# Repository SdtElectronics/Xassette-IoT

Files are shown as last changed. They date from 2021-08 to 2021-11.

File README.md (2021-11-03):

# Xassette IoT
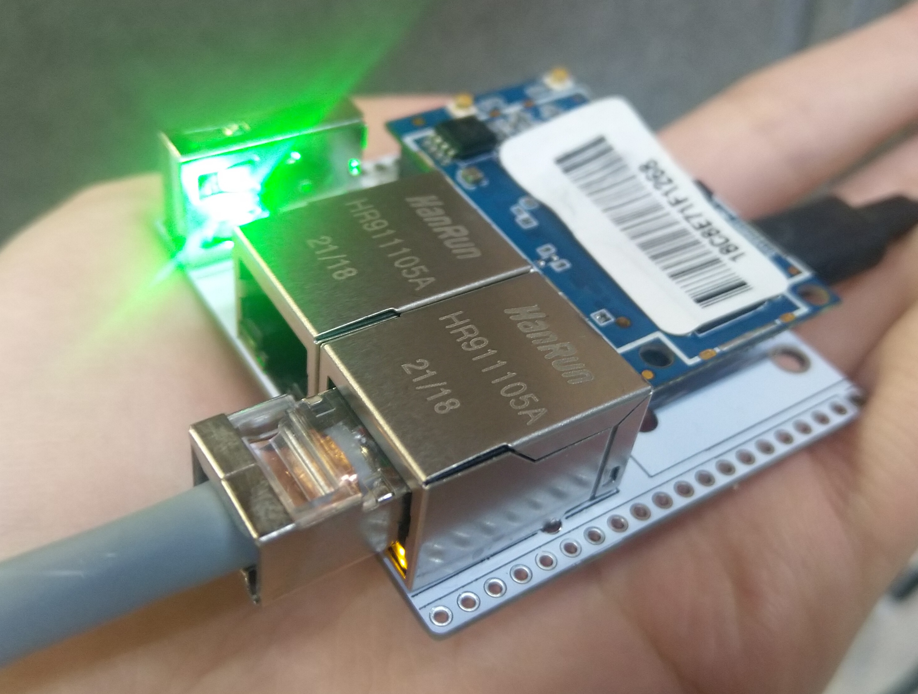
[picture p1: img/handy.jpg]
handy

## Hardware Resources
* SoC: MediaTek MT7628 1xMIPS 24Kc@580Mhz
* RAM: 64MB DDR2
* ROM: 8M SPI flash EN25Q64
* WLAN: 802.11n, 2T2R, speed up to 300Mbps
* EPHY: 5×100M with 2 onboard RJ-45 ports
* USB: 1×USB2.0 HS
* Connectivity: 2×UART¹, 1×I2C, 1×I2S, 1×SPI², 1×SDIO³, 4×PWM

Note:
1. UART1 is used as debug serial at baud rate 57600 with default firmware
2. Shared with onboard NOR flash
3. Supports SDXC up to 2TB

## Flashing New Firmware
* See [Guide on Firmware](docs/fwGuide.md)

## Build New Firmware From Source
* See [Build From Scratch](docs/buildingGuide.md)

## Schematic
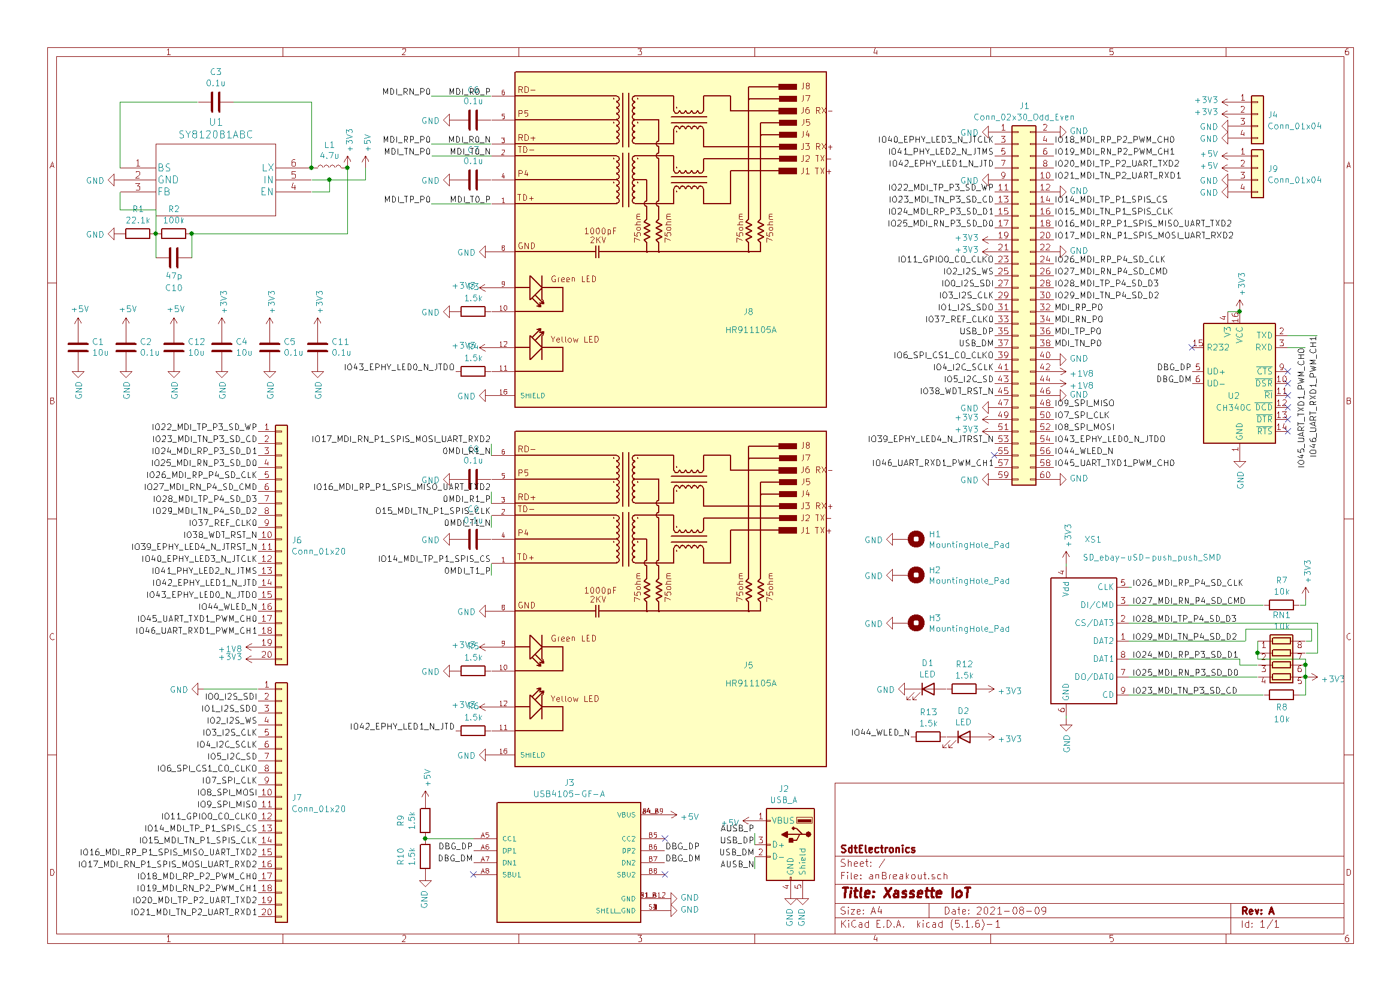
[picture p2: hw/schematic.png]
sch


PDF format is available at [hw/anBreakout.pdf](hw/anBreakout.pdf)

Note: `IOxx` in the schematic as well as the silk numbers onboard correspond to the GPIO indices in the table below.

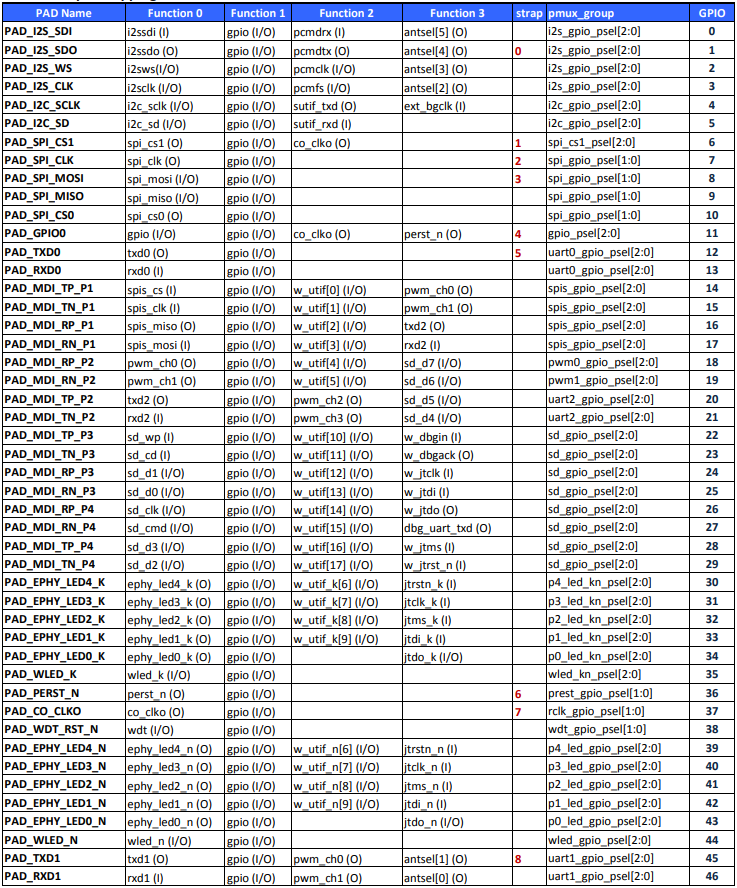
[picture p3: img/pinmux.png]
pinmux


## Board Gerber
See [Releases](https://github.com/SdtElectronics/Xassette-IoT/releases/)

## Errata
In v0.2
* Silk text error: MDI1 should be MDI2
* Net error: 1V8 is not connected
* Annotation and silk text error: pin45 should be pin12
* Annotation and silk text error: pin46 should be pin13

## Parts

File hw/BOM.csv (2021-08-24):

Comment | Designator | Footprint | Pins | Quantity
47p | C10, | C_0603_1608Metric | 2 | 1
0.1u | C11,C3, | C_0603_1608Metric | 2 | 2
10u | C12,C4, | C_0805_2012Metric | 2 | 2
LED | D2,D1, | LED_0603_1608Metric | 2 | 2
Conn_02x30_Odd_Even | J1, | PinSocket_2x30_P1.27mm_Vertical_SMD | 60 | 1
4.7u | L1, | L_0420 | 2 | 1
22.1k | R1, | R_0603_1608Metric | 2 | 1
1.5k | R12,R10,R9, | R_0603_1608Metric | 2 | 3
100k | R2, | R_0603_1608Metric | 2 | 1
SY8120B1ABC | U1, | SOT-23-6 | 6 | 1
CH340C | U2, | SOIC-16_3.9x9.9mm_P1.27mm | 16 | 1
10u | C1, | C_0805_2012Metric | 2 | 1
0.1u | C9,C8,C7,C6,C5,C2, | C_0603_1608Metric | 2 | 6
1.5k | R13,R6,R5,R4,R3, | R_0603_1608Metric | 2 | 5
10k | R8,R7, | R_0603_1608Metric | 2 | 2
10k | RN1, | R_Array_Convex_4x0603 | 8 | 1
Through Hole Items
USB_A | J2, | USB_A_Wuerth_614004134726_Horizontal | 8 | 1
USB4105-GF-A | J3, | GCT_USB4105-GF-A | 18 | 1
Conn_01x20 | J7,J6, | PinHeader_1x20_P2.54mm_Vertical | 20 | 2
HR911105A | J8,J5, | HANRUN_HR911105A | 16 | 2
Conn_01x04 | J9,J4, | PinHeader_1x04_P2.54mm_Horizontal | 4 | 2
uSD-push_push_SMD | XS1, | Conn_uSDcard | 15 | 1

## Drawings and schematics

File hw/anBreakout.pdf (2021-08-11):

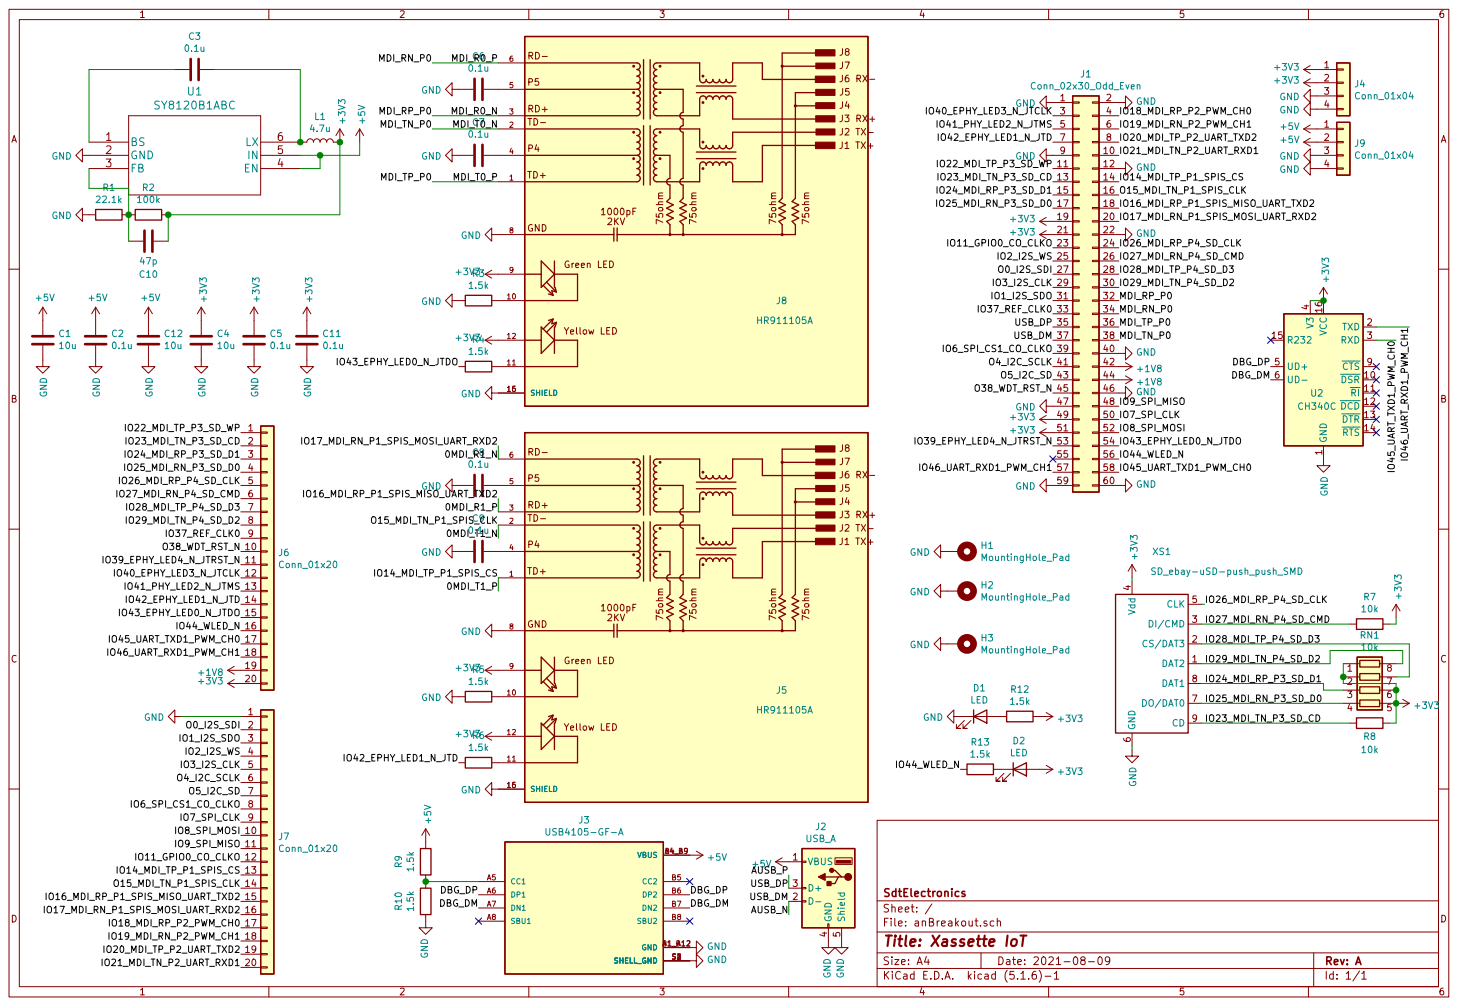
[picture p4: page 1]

4 UD+ 5 UD- 6 CTS 9 U2 CH340C GND

1 DSR 10 RI 11 DCD 12 DTR 13 RTS 14 R232 15 VCC 16 TXD 2 RXD 3 V3

File: anBreakout.sch Sheet: / SdtElectronics

Id: 1/1 Title: Xassette IoT

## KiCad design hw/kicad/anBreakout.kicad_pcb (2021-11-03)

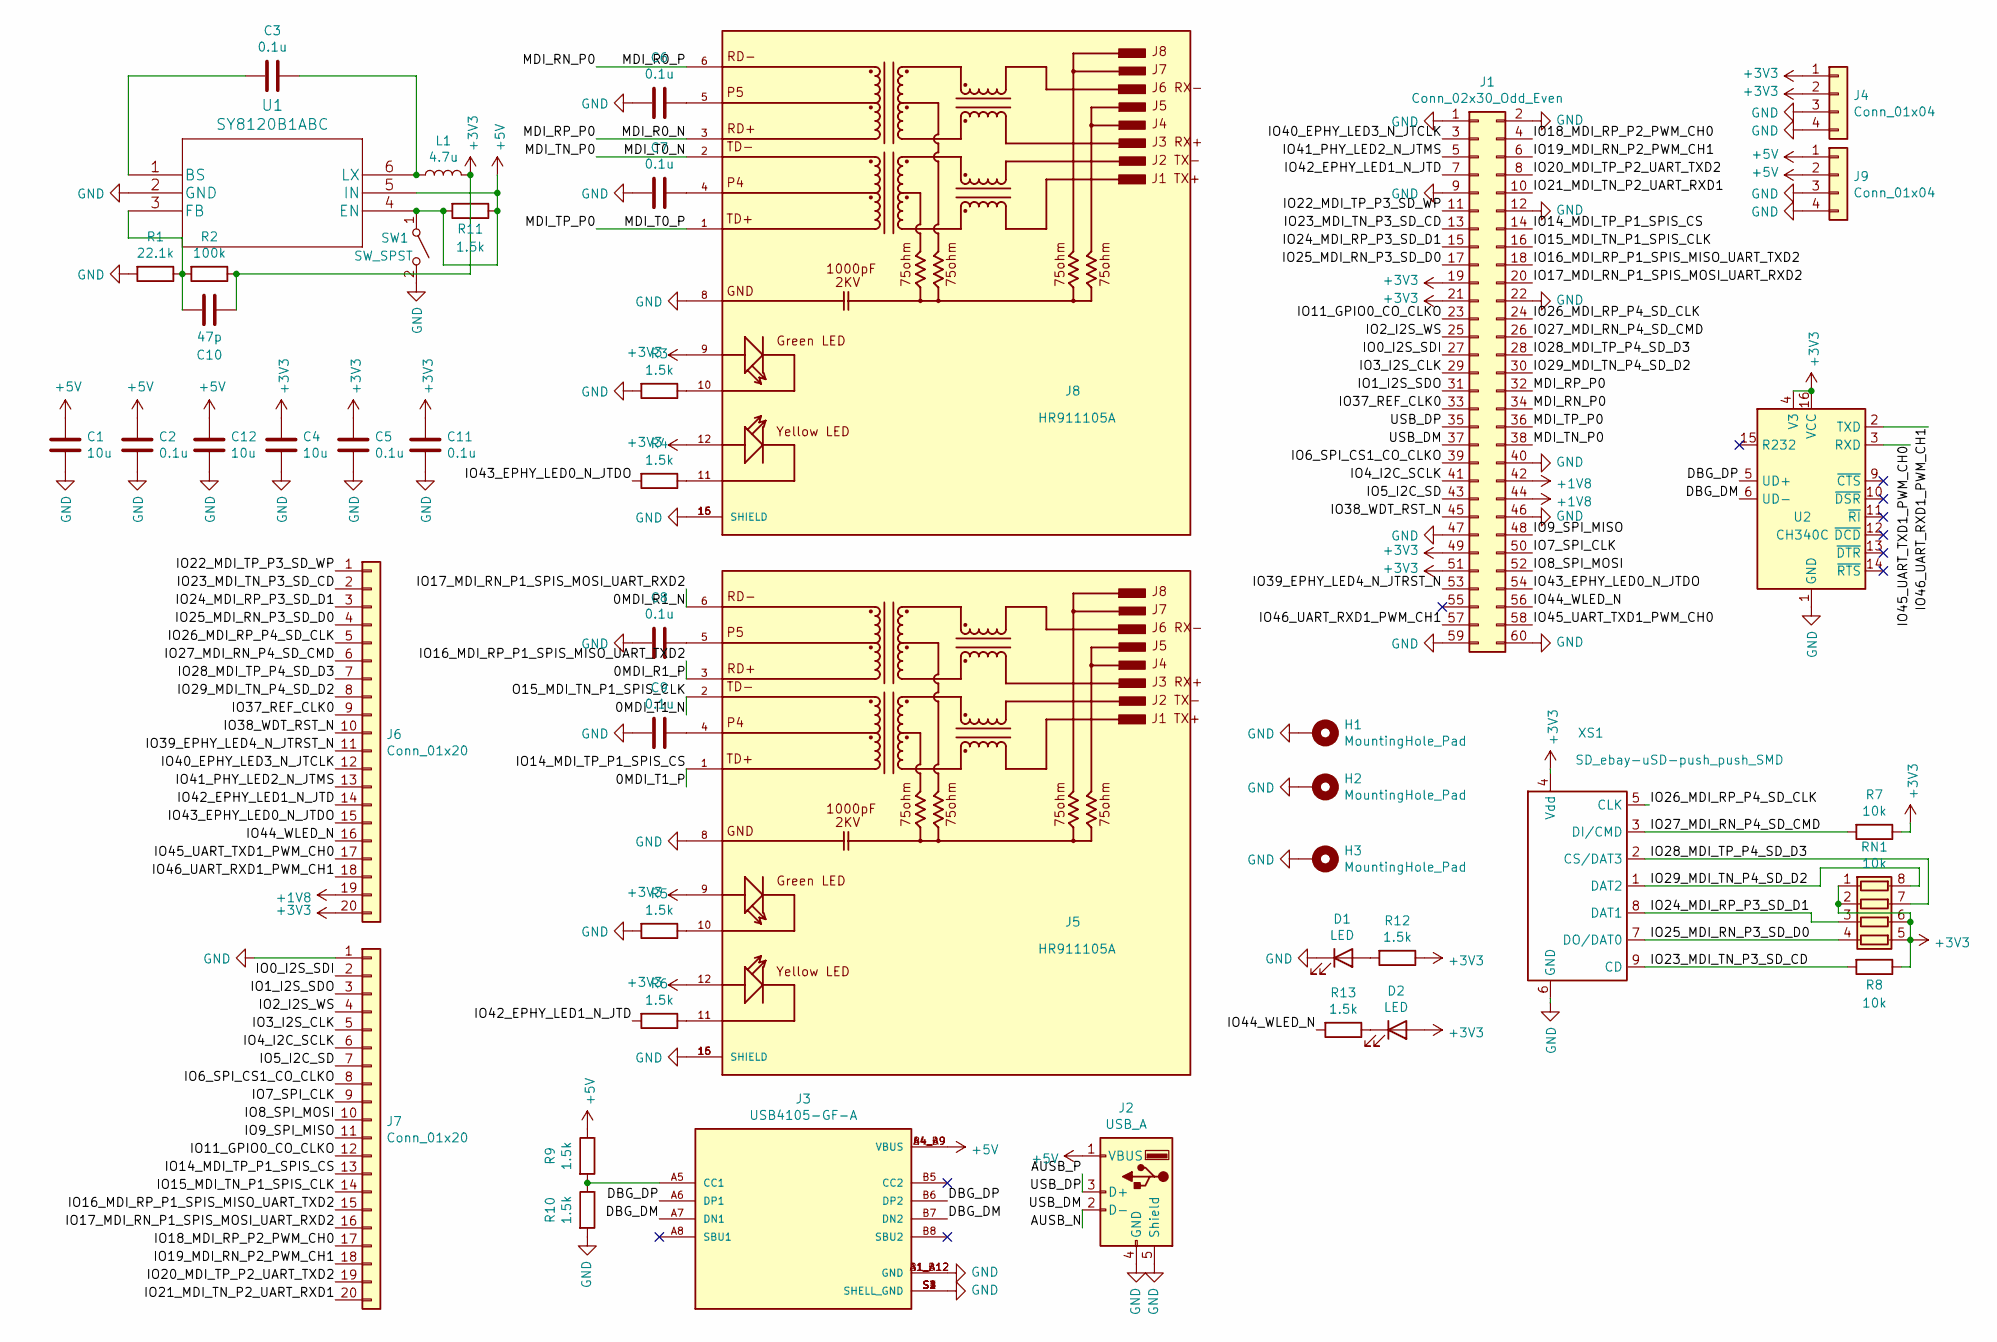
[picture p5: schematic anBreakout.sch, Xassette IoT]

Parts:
C1, C4, C12: 10u; C_0805_2012Metric
C2, C3, C5, C6, C7, C8, C9, C11: 0.1u; C_0603_1608Metric
C10: 47p; C_0603_1608Metric
D1, D2: LED; LED_0603_1608Metric
H1, H2, H3: MountingHole_Pad; MountingHole_3.2mm_M3_Pad
J1: Conn_02x30_Odd_Even; PinSocket_2x30_P1.27mm_Vertical_SMD
J2: USB_A; USB_A_Wuerth_614004134726_Horizontal
J3: USB4105-GF-A; GCT_USB4105-GF-A; PARTREV A3
J4, J9: Conn_01x04; PinHeader_1x04_P2.54mm_Horizontal
J5, J8: HR911105A; HANRUN_HR911105A; PARTREV A
J6, J7: Conn_01x20; PinHeader_1x20_P2.54mm_Vertical
L1: 4.7u; L_Taiyo-Yuden_MD-4040
R1: 22.1k; R_0603_1608Metric
R2: 100k; R_0603_1608Metric
R3, R4, R5, R6, R9, R10, R11, R12, R13: 1.5k; R_0603_1608Metric
R7, R8: 10k; R_0603_1608Metric
RN1: 10k; R_Array_Convex_4x0603
SW1: SW_SPST; SW_SPST_FSMSM
U1: SY8120B1ABC; SOT-23-6
U2: CH340C; SOIC-16_3.9x9.9mm_P1.27mm
XS1: SD_ebay-uSD-push_push_SMD; Conn_uSDcard

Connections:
+1V8: J1.42, J1.44, J6.19
+3V3: C4.2, C5.2, C10.1, C11.2, D2.2 (A), J1.19, J1.21, J1.49, J1.51, J4.1, J4.2, J5.9, J5.12, J6.20, J8.9, J8.12, L1.2, R2.1, R7.1, R8.1, R12.1, RN1.1 (R1.1), RN1.2 (R2.1), RN1.5 (R4.2), RN1.6 (R3.2), U2.4 (V3), U2.16 (VCC), XS1.4 (Vdd)
+5V: C1.2, C2.2, C12.2, J2.1 (VBUS), J3.A4_B9 (VBUS), J3.B4_A9 (VBUS), J9.1, J9.2, R9.1, R11.1, R11.2, SW1.1 (A), U1.4 (EN), U1.5 (IN)
/0MDI_R1_N: J1.20, J5.6, J7.16
/0MDI_R1_P: J1.18, J5.3, J7.15
/0MDI_T1_P: J1.14, J5.1, J7.13
/AUSB_N: J1.37, J2.2 (D-)
/AUSB_P: J1.35, J2.3 (D+)
/DBG_DM: J3.A7 (DN1), J3.B7 (DN2), U2.6 (UD-)
/DBG_DP: J3.A6 (DP1), J3.B6 (DP2), U2.5 (UD+)
/IO1_I2S_SDO: J1.31, J7.3
/IO2_I2S_WS: J1.25, J7.4
/IO3_I2S_CLK: J1.29, J7.5
/IO6_SPI_CS1_CO_CLKO: J1.39, J7.8
/IO7_SPI_CLK: J1.50, J7.9
/IO8_SPI_MOSI: J1.52, J7.10
/IO9_SPI_MISO: J1.48, J7.11
/IO11_GPIO0_CO_CLKO: J1.23, J7.12
/IO18_MDI_RP_P2_PWM_CH0: J1.4, J7.17
/IO19_MDI_RN_P2_PWM_CH1: J1.6, J7.18
/IO20_MDI_TP_P2_UART_TXD2: J1.8, J7.19
/IO21_MDI_TN_P2_UART_RXD1: J1.10, J7.20
/IO22_MDI_TP_P3_SD_WP: J1.11, J6.1
/IO23_MDI_TN_P3_SD_CD: J1.13, J6.2, R8.2, XS1.9 (CD)
/IO24_MDI_RP_P3_SD_D1: J1.15, J6.3, RN1.3 (R3.1), XS1.8 (DAT1)
/IO25_MDI_RN_P3_SD_D0: J1.17, J6.4, RN1.4 (R4.1), XS1.7 (DO/DAT0)
/IO26_MDI_RP_P4_SD_CLK: J1.24, J6.5, XS1.5 (CLK)
/IO27_MDI_RN_P4_SD_CMD: J1.26, J6.6, R7.2, XS1.3 (DI/CMD)
/IO28_MDI_TP_P4_SD_D3: J1.28, J6.7, RN1.7 (R2.2), XS1.2 (CS/DAT3)
/IO29_MDI_TN_P4_SD_D2: J1.30, J6.8, RN1.8 (R1.2), XS1.1 (DAT2)
/IO37_REF_CLK0: J1.33, J6.9
/IO39_EPHY_LED4_N_JTRST_N: J1.53, J6.11
/IO40_EPHY_LED3_N_JTCLK: J1.3, J6.12
/IO41_PHY_LED2_N_JTMS: J1.5, J6.13
/IO42_EPHY_LED1_N_JTD: J1.7, J6.14, R6.2
/IO43_EPHY_LED0_N_JTDO: J1.54, J6.15, R4.2
/IO44_WLED_N: J1.56, J6.16, R13.2
/IO45_UART_TXD1_PWM_CH0: J1.58, J6.17, U2.3 (RXD)
/IO46_UART_RXD1_PWM_CH1: J1.57, J6.18, U2.2 (TXD)
/MDI_R0_N: J1.32, J8.3
/MDI_R0_P: J1.34, J8.6
/MDI_T0_N: J1.38, J8.2
/MDI_T0_P: J1.36, J8.1
/O0_I2S_SDI: J1.27, J7.2
/O4_I2C_SCLK: J1.41, J7.6
/O5_I2C_SD: J1.43, J7.7
/O38_WDT_RST_N: J1.45, J6.10
GND: C1.1, C2.1, C4.1, C5.1, C6.2, C7.2, C8.2, C9.2, C11.1, C12.1, D1.1 (K), H1.1, H2.1, H3.1, J1.1, J1.2, J1.9, J1.12, J1.22, J1.40, J1.46, J1.47, J1.59, J1.60, J2.4 (GND), J2.5 (Shield), J3.A1_B12 (GND), J3.B1_A12 (GND), J3.S1 (SHELL_GND), J3.S2 (SHELL_GND), J3.S3 (SHELL_GND), J3.S4 (SHELL_GND), J4.3, J4.4, J5.8, J5.15 (SHIELD), J5.16 (SHIELD), J7.1, J8.8, J8.15 (SHIELD), J8.16 (SHIELD), J9.3, J9.4, R1.2, R3.2, R5.2, R10.2, SW1.2 (B), U1.2 (GND), U2.1 (GND), XS1.6 (GND)
unnamed: C3.1, L1.1, U1.6 (LX)
unnamed: C3.2, U1.1 (BS)
unnamed: C6.1, J8.5
unnamed: C7.1, J8.4
unnamed: C8.1, J5.5
unnamed: C9.1, J5.4
unnamed: C10.2, R1.1, R2.2, U1.3 (FB)
unnamed: D1.2 (A), R12.2
unnamed: D2.1 (K), R13.1
unnamed: J3.A5 (CC1), R9.2, R10.1
unnamed: J5.10, R5.1
unnamed: J5.11, R6.1
unnamed: J8.10, R3.1
unnamed: J8.11, R4.1

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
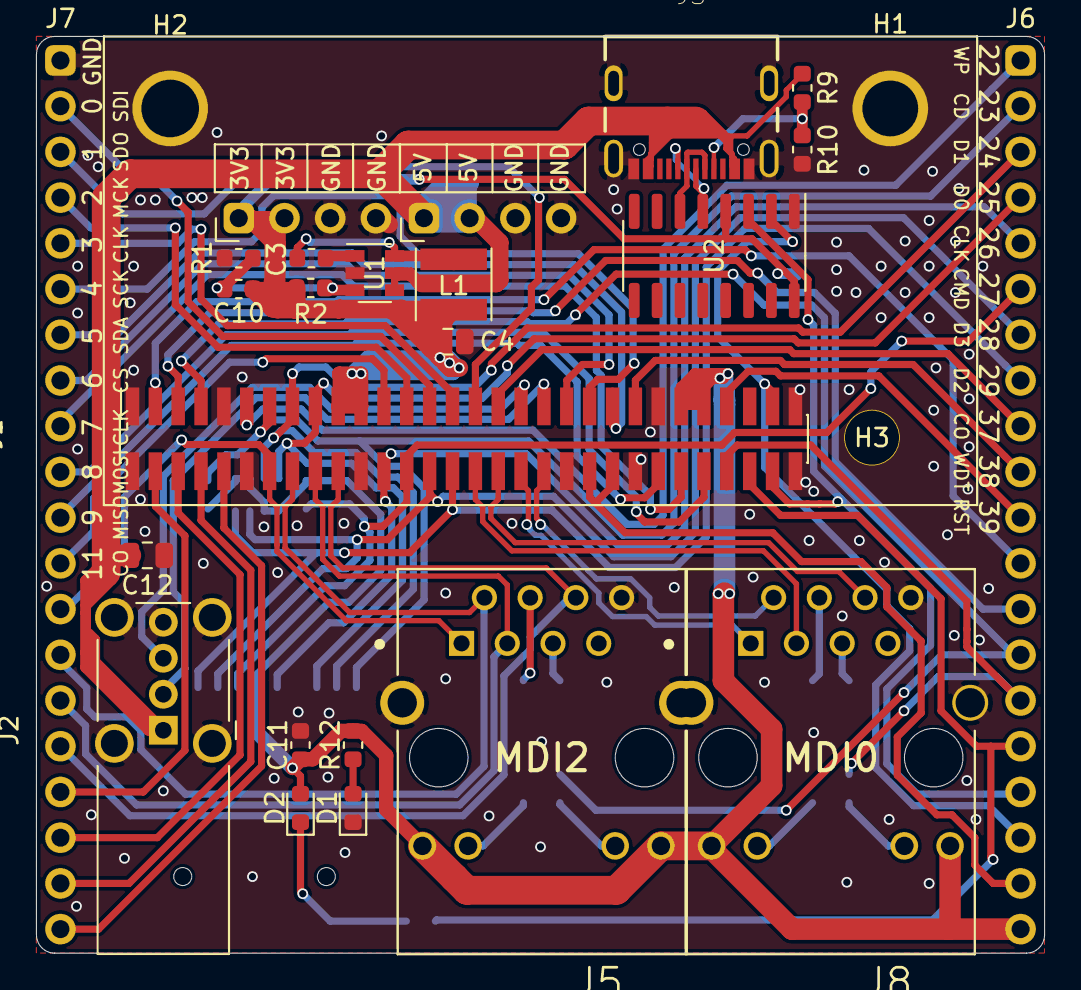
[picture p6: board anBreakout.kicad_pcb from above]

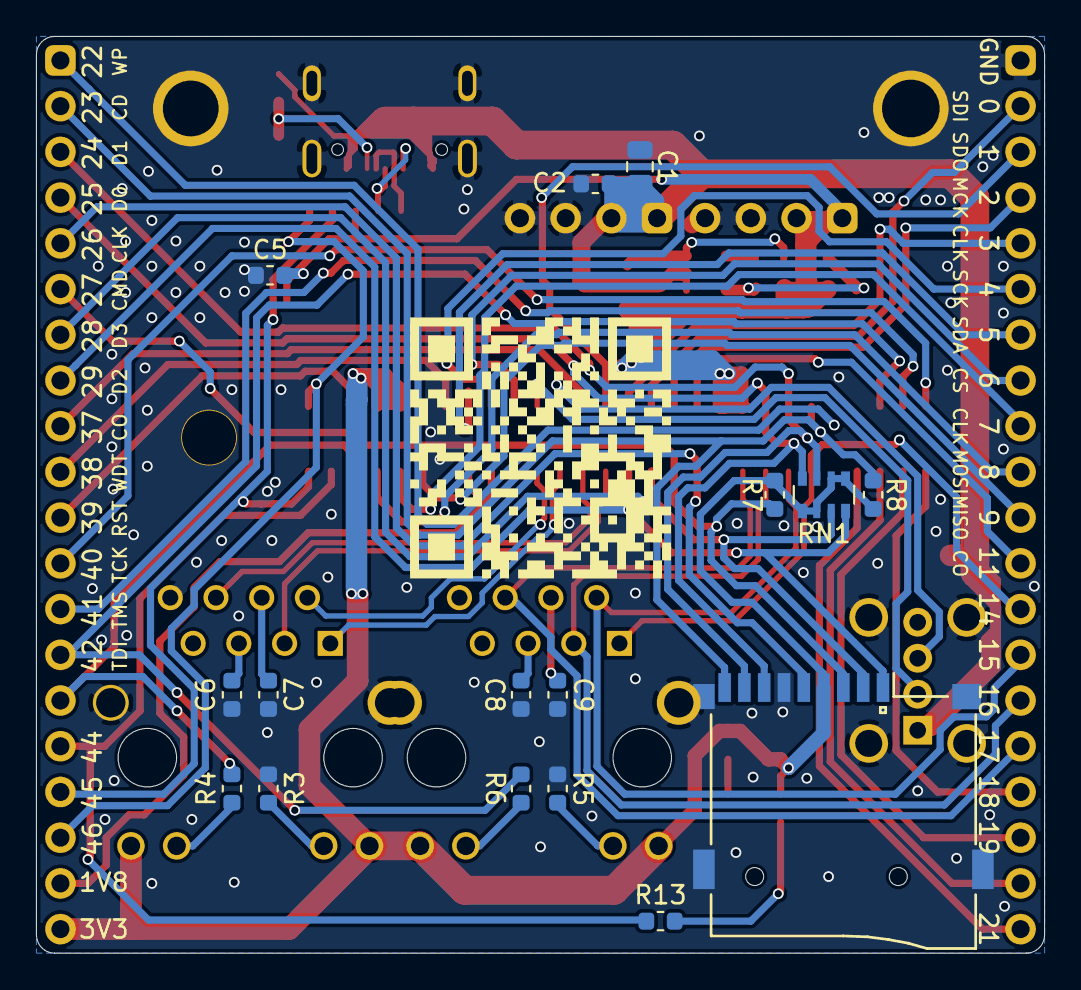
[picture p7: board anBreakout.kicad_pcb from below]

Board: 2 copper layers, 56.0 x 50.9 mm, 44 parts (17 on the bottom side), 63 nets.

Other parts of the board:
QR*****: https://github.com/SdtElectronics; __github.com_SdtElectronics

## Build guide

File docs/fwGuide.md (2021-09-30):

# Guide on Firmware
## Factory Partition Backup (IMPORTANT)
The wireless calibration file (aka ART file) resides in the factory partition of original firmware. If you proceed with altering the original firmware without backing up this partition, you are at the risk of permanent loss of the calibration data. Therefore, be sure you have backed up this partition before flashing your device!

Connect to the type-C port and your PC should be able to probe the onboard USB-Serial interface. Windows users may need to install CH340 driver manually. The configuration of serial is 57600bps, 8bits, no even, 1 stop bit. Open a serial terminal on your PC and run following command:

```
cat /dev/mtd2 > /tmp/art.bin
```

Then connect to one of RJ45 Ports, and run following command:

```
ifconfig eth2 192.168.100.1
tcpsvd -vE 0.0.0.0 21 ftpd /tmp
```

Set the IP of the interface on your PC which connected to the board to `192.168.100.2`, and your PC are ready to establish network connection with the board. You can run `ping` to verify the link, or proceed to access `ftp://192.168.100.1` with a file explorer. You should find a file named `art.bin` there and copy it to the storage of your PC.

## Flashing New Firmware
The original firmware runs a archaic linux 2.6 kernel and provides quite limited functionality, thus it is preferred to flash a new system. The original u-boot is capable to do this therefore it's unnecessary to upgrade it. Candidates of OpenWRT firmware should be compatible with `ramips MT7620` SoC and come with names like `xxx-squashfs-sysupgrade.bin`.

Connect to the type-C port and your PC should be able to probe the onboard USB-Serial interface. Open a serial terminal on your PC and run `reboot` to enter the bootloader. Press `2` right after the board is restarted and you will see instructions leading you to upgrade the system. Then connect to one of the RJ45 Ports and set the IP of the interface on your PC which connected to the board to `192.168.1.10`. Run a tftp server on your PC and move the firmware to the root path of the server. Rename the firmware to `fw.bin`. Head back to the terminal and leave the default configurations unchanged and proceed with `Enter`. Now a progress bar should appear on the terminal. Wait until it is finished and it will reboot to the new system.

## Setup opkg
If you opt into an OpenWRT firmware, the package manager is the most convenient way to get new softwares. But it requires some configuration before using:

Switch the source mirror:
```
sed -i 's_downloads.openwrt.org_mirrors.tuna.tsinghua.edu.cn/openwrt_' /etc/opkg/distfeeds.conf
```

Update the source:

```
opkg update
```

## Flash Operation with SPI Programmer
In some cases you may want to directly access the onboard flash. Without removing it from board, clamp it with a programmer will cause troubles as the SoC is powered up and confuses the programmer. One walk-around is to use `poweroff` command to shutdown the SoC in advance. If the device is already bricked and that is no longer feasible, use a soldering iron to make the `VCC` or `GND` pin of the flash float works as well.

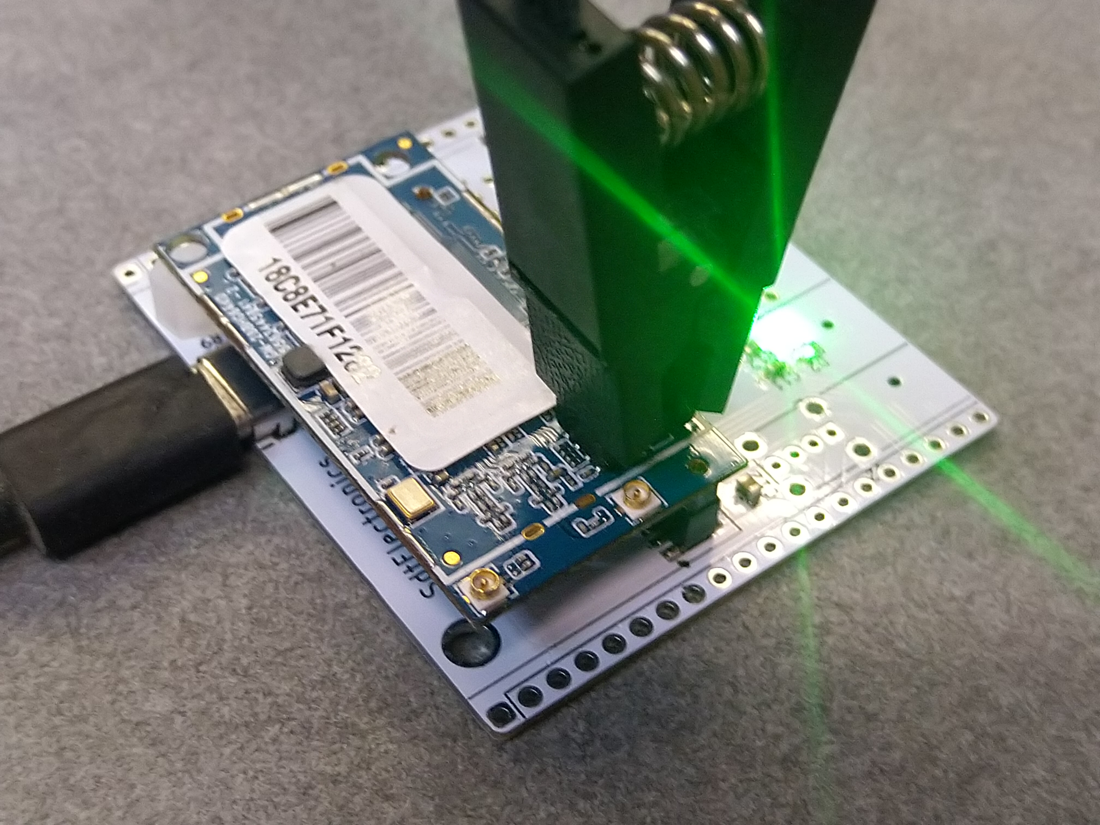
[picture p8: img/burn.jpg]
handy


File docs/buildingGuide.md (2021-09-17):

# Build From Scratch
## Dependencies
### For Debian users:
```
$ sudo apt-get update 
$ sudo apt-get install git g++ make libncurses5-dev subversion libssl-dev gawk libxml-parser-perl unzip wget python xz-utils vim zlibc zlib1g zlib1g-dev openjdk-8-jdk build-essential ccache gettext xsltproc
```
### Extra operations for Debian 64bit:
```
$ sudo dpkg --add-architecture i386
$ sudo apt-get update
$ sudo apt-get install libc6:i386 libncurses5:i386 libstdc++6:i386
```
### For ArchLinux users:
```
$ vim /etc/pacman.conf 
    # Uncomment these:
    [multilib]
    Include = /etc/pacman.d/mirrorlist

$ sudo pacman -S base-devel subversion asciidoc b43-fwcutter bash bc bin86 boost binutils bzip2 cdrkit fastjar flex gawk gettext git gtk2 intltool jdk7-openjdk libusb libxslt ncurses openssl patch perl python2 rsync ruby sdcc sharutils unzip util-linux wget zlib gcc make perl-extutils-makemaker findutils libstdc++5 lib32-libstdc++5 gperf
```

## U-Boot
U-Boot from widora almost works out of the box, the only thing we need to do is to modify the size of DDR RAM.

### 1. Grab the code:
```
$ git clone https://github.com/widora/u-boot-mt7688.git
```
### 2. Extract toolchain:
```
$ cd u-boot-mt7688
$ sudo tar xvfj buildroot-gcc342.tar.bz2 -C /opt/
```
Install openjdk:
```
$ sudo apt install openjdk-8-jdk
or $ sudo pacman -S jdk8-openjdk
```

### 3. Build
Configure DDR:
```
$ make menuconfig
```
Change "DDR Component" entry to 512Mb

Build:
```
$ make clean;make
```
The output file would be 'uboot.bin'

## OpenWrt
### 1. Grab the code:
```
$ git clone https://github.com/widora/openwrt.git
```
### 2. Update feeds:
```
$ ./scripts/feeds update -a && ./scripts/feeds install -a
```
### 3. Configure OpenWrt:
```
$ rm .config
$ make menuconfig
```
Chose:
```
Target System: MediaTek Ralink MIPS 
  Subtarget: MT76x8 based boards 
     Target Profile: Widora-NEO(16M) 
```
NOTE: You need to swap the onboard spi flash with a 16M one, or manually change the mtd partition table in device tree.
### 4. Build:
```
$ make -j4
```

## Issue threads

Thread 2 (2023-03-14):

57600bps UART1 编译的固件bin文件能分享吗？

QGB, 2023-03-14:
MT7688核心板  内存32MB  Flash 8MB

openwrt官网上说：
```
随着时间的推移，支持低 Flash + RAM 的设备变得越来越困难甚至不可能。您将不太可能在论坛上找到愿意提供帮助的人。

32 MB RAM 比闪存大小更难限制。当前的 Linux 5.4 几乎无法与 32 MB RAM 系统配合使用，内存消耗的峰值很容易导致路由器崩溃并出现 OOM（内存不足）错误。

OpenWrt 对这些设备的支持已经在 19.07 版本中结束，即。19.07 是支持 4/32 MB设备的最后一个版本。19.07 之后没有未来版本，也没有可供下载的图像。
```

版本19.07 ， 57600bps UART1 编译的固件bin文件能分享吗？

uboot 里面有一个 tftpboot- boot image via network using TFTP protocol

这个可以用来启动而不写入flash吗？我想先试试固件行不行

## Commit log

2021-08-21 add BOM List
    [BOM.csv]
2021-08-21 update schematic
2021-08-24 add errata
    [BOM.csv]
2021-09-30 amend uart pin index
2021-11-03 disclosure pcb sources
    [anBreakout.kicad_pcb, anBreakout.sch]
